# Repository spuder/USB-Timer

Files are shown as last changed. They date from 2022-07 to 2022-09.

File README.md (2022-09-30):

# USB-Timer

Control 4 USB ports with a microcontroller








Buy your own:   




## Hardware

USB-Timer is based on a Wemos D1 Mini. It uses 4 N Channel Mosfets to control multiple USB ports

| **Microcontroller**: | Count | 
| --- | --- |
| [Wemos D1 Mini](https://www.amazon.com/MakerFocus-NodeMcu-Development-ESP8266-Compatible/dp/B07KW54YSK) | 1x | 

| **Mosfets**: | Type | Count | 
| --- | --- | --- |
| [IRLZ34N N Channel Mosfet ](https://www.amazon.com/BOJACK-IRLZ34N-IRLZ34NPBF-N-Channel-transistors/dp/B08L8S3154) |Through Hole| 4x|
| [NTR4501NT1G N Channel Mosfet](https://www.mouser.com/ProductDetail/863-NTR4501NT1G) |SMD | 4x |

Use either through hole _or_ SMD mosfet, not both!
*Any TTL N Channel Mosfet should work as long as it has a VGO < 3.3. volts*

| **Resitors**  | Count | 
| ---  | --- |
| [10K - 1/4 watt](https://www.mouser.com/ProductDetail/Vishay-Beyschlag/MBA02040C1002FC100?qs=nlQjf3QnJCoHnMMMaOw%2FFA%3D%3D) | 8x | 

| **USB** | Website | Count |
| --- | --- | --- |
| [USB Type A Connector](https://www.amazon.com/gp/product/B00H51E7B0/ref=ewc_pr_img_3?smid=ATVPDKIKX0DER&psc=1) | Amazon | 4x | 
| [USB mini](https://www.mouser.com/ProductDetail/798-ZX62D-B-5PA830) | Mouser | 1x | 
| [USB Mini Easy Solder](https://www.amazon.com/Micro-Interface-Adapter-Breakout-Module/dp/B07B5ZDLJY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) | Amazon | 1x | 

| **Buttons (optional)** | Website | Count | 
| --- | --- | --- |
| [8mm metal buttons](https://www.aliexpress.com/item/3256801677651364.html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) | Aliexpress | 4
| [Rubber Feet](https://www.amazon.com/gp/product/B07G86DL1L/ref=ppx_yo_dt_b_asin_title_o00_s00?ie=UTF8&psc=1) | Amazon | 100| 

See [PCB/BOM](./PCB/BOM) for full Bill of Materials

### Schematic





Board was designed with [Easy EDA](https://easyeda.com/)

View project on [OSHWLab.com/owenspencer/USB-Timer](https://oshwlab.com/owenspencer/USB-Timer)





### Building

Order the PCB from your favorite PCB Manufacture. Cost of boards will be about $27 for 5

Popular Choices: 
- [OshPark](https://oshpark.com/)
- [JLCPCB](https://jlcpcb.com/)
- [PCBWay](https://www.pcbway.com/)

The board can be built with either surface mount or through hole components (but not both). 

For the micro USB ports, you can solder the ports directly (if you are skilled), or you can use [these through hole kits](https://www.amazon.com/gp/product/B07KS1RPMP/ref=ewc_pr_img_2?smid=AB5D7200EYCEL&psc=1)



### PinOut

```sh
USB 1 => D8 
USB 2 => D7
USB 3 => D6
USB 4 => D5
Button 1 => D1 and GND (PullUp)
Button 2 => D2 and GND (PullUp)
Button 3 => D3 and GND (PullUp)
Button 4 => D0 and 3.3v (PullDown)
```


Once the board is built, see the [Firmware/arduino/blink/README.md](Firmware/arduino/blink/README.md]) for a sketch to blink the leds. Or get started with ESPHome configuration. 

[Setup D1 Mini with arduino](https://www.instructables.com/Programming-the-WeMos-Using-Arduino-SoftwareIDE/)  

## Configuration

Configuration can be done in one of several ways

1. web.esphome.com (recomended for most users)
2. ESPHome / ESPHome + Home Assistant 
3. Arudino programming (advanced)



### Config[ESPHome]

### Web.esphome.com

The easiest way to get up and running is by plugging the USB-Timer into your computer, then navigating to [https://web.esphome.io/](https://web.esphome.io/)

Then upload the `firmware.bin` available from the releases page. 

Once the device reboots, you should find a new wireless network named 'USB-Timer Fallback Network'.

Password => `12345678`

#### Home Assistant

Setting up with HomeAssistant is easy, just install the esphome extension, then click 'add device'. 

See [./Firmware/esphome](./Firmware/esphome/) directory for example configurations

Most of the configuration is abstracted away so you don't need to worry about it. 

Some versions of home assistant default to the wrong model of esp8266. If you get errors, try commenting/deleting these lines. (or rename `esp01_1m` to  `d1_mini` )

```bash
#esp8266:
# board: esp01_1m
```

Just add an 'include' into your esphome config that references this git repo and esphome should set everything up automatically including your timezone.

```yaml
packages:
  usb-timer: github://spuder/USB-Timer/Firmware/esphome/packages/hardware.yaml
dashboard_import:
  package_import_url: github://spuder/usb-timer/esphome/common.yaml@main
```

Copy the api key from the HA gui and then go to 'Settings' -> 'Integrations' and you should see a new device named usb-timer1 (or whatever you named it). Paste in your api key and everything should work. 

---

#### ESPHome Stand Alone (non home assistant)

A `Makefile` is provided that will generate `firmware.bin` file which you can manually upload to your USB-Timer. 

Make sure you have `esphome` installed. OSX Users with homebrew can run `brew install esphome`. 

```bash
make clean
make build
```

This will generate 2 firmware files in the root directory

```bash
firmware.bin
firmware.elf
```

Use a tool like [https://web.esphome.io/](https://web.esphome.io/) or [esphome/esphome-flasher](https://github.com/esphome/esphome-flasher) to upload the .bin to the wemos d1 mini

If you didn't specify a wireless network, the wemos will boot up into AP mode. Join the network named 'USB-Timer Fallback Hotspot' with password `12345678`. 

A captive portal will popup which will allow you to reconfigure the device to your wifi network. 



### Config[Firmware/arduino]

Code examples located in the arduino folder (Advanced users only, esphome is recomended for most users)

- [Firmware/arduino](./Firmware/arduino)  
- [Firmware/arduino/blink/README.md](arduino/blink/README.md])  
- [Firmware/arduino/wifi_manager/README.md](arduino/wifi_manager/README.md])  

## Case

STL files for a 3d printable case are located in the [CAD](./CAD/) folder



## License

This is released under the [GNU license](https://choosealicense.com/licenses/gpl-3.0/). 
You may modify and even sell comercial products, as long as it remains open source (closed source derivitives are prohibited).

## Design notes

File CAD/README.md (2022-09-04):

# CAD

The cad folder contains

- stl of pcb
- f3d files of pcb
- zip files exports from EasyEDA

The stl and f3d files were converted from EasyEDA and are only inteded to be used as rough guide for desiging cases. 

The STL's had to be converted multiple times and should not be trusted as accurate. (PCB-full is off by 1.5%). Hole placements are not guaranteed to be accurate on either model. 

Use PCB-simple since it is the more accurate of the 2 stl files. 

## Feet

The bottom has cutouts for 8mm rubber feet



[Amazon - Rubber Feet](https://www.amazon.com/gp/product/B07G86DL1L/ref=ppx_yo_dt_b_asin_title_o00_s00?ie=UTF8&psc=1)

## Assembly

Use 2 (optional) m3 screws to hold the lid in place.



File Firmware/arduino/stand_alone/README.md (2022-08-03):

# stand_alone

Stand alone is an arduino sketch to programtically turn on and off the usb ports on a schedule. 
It synchronizes with an NTP server

wifi_manager is more intellegent and is easier for many people to interface with. However it is currently a work in progress.

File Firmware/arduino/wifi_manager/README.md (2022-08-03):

# Wifi Manager

**Work in Progress**

Many features are stil being worked on. Pull requests welcome

## Objective: Program the USB-Timer without needing a computer

1. Join the Wifi Network named 'USB-Timer'
2. Navigate to the ip address of the device (iOS will automatcially open a captive portal)
3. Program in the times you want the device to turn on and off





## Reconfiguration

To reconfigure, navigate to the ip address of the device on your network

Alternativly press the physical button on the corner of the USB-Timer PCB. A wireless network will appear named USB-Timer. Once done configuring, reboot and the network will disappear.

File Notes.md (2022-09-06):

## Resources

- Add USB C to your usb 2.0 projects https://idyl.io/how-to-add-usb-type-c-micro-usb-replacement/

- [Alternative USB Micro Kit](https://www.amazon.com/Teansic-24Models-Connector-Connectors-Samsung/dp/B089Q99ZHS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)

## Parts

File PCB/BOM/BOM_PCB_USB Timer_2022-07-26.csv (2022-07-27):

ID | Name | Designator | Footprint | Quantity | Manufacturer Part | Manufacturer | Supplier | Supplier Part | Price
1 | NTR4501NT1G | Q1-B,Q2-B,Q3-B,Q4-B | SOT-23-3_L2.9-W1.3-P1.90-LS2.4-BR | 4 | NTR4501NT1G | ON | LCSC | C85416 | 0.134
2 | Header-5x1-2.54mm | U5,U6,U7,U8 | HEADER-5X1-2.54MM | 4
3 | LED_5MM | LED1,LED2,LED3,LED4 | LED-TH_BD5.0-P2.54-FD_C9900023552 | 4 | LED_5MM | null | LCSC | C9900023552
4 | IRLZ34N | Q1-A,Q2-A,Q3-A,Q4-A | IRLZ34N | 4
5 | 330Ω | R1,R3,R5,R7 | AXIAL-0.6 | 4 | EWWR0001J20R0T9 | ResistorToday | LCSC | X16151710
6 | 10KΩ | R2,R4,R6,R8 | AXIAL-0.6 | 4 | EWWR0001J20R0T9 | ResistorToday | LCSC | X16151710
7 | Header-8x1-2.54mm | U1,U2 | HEADER-8X1-2.54MM | 2
8 | Button-6x6x8-Right-Angle | SW1 | SW-TH_BBJ-C71833 | 1 | 6*6*8Plastic head,260G, 0.25mm,Side bracket | BBJ | LCSC | C71833 | 0.023
9 | Button-6x6x6mm | SW2 | SW-TH_4P-L6.0-W6.0-P4.50-LS6.1 | 1 | Switch,6*6*6Plastic head,260G, 0.25mm,Straight line | BBJ | LCSC | C71836 | 0.017
10 | EduCiaaPE_OSHWA | #G1 | LOGO_OSHWA | 1
11 | JTJ-USB-AF-90-07 | USB3_TH,USB5_TH,USB7_TH,USB1_TH | USB-A-TH_C42650 | 4 | JTJ-USB-AF-90-07 | LCSC | LCSC | C42650 | 0.041
12 | WEMOS-D1-MINI | 1 | WEMOS-D1-MINI | 1
13 | ZX62D-B-5PA8(30) | USB2,USB4,USB6,USB8 | MICRO-USB-SMD_ZX62D-B-5PA8-30 | 4 | ZX62D-B-5PA8(30) | HRS(Hirose) | LCSC | C132350 | 0.299

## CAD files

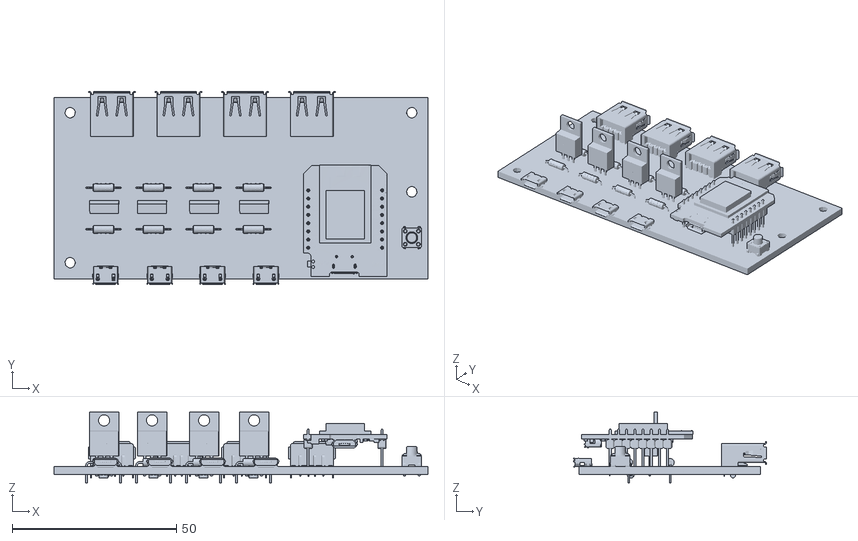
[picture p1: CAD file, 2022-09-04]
CAD/PCB/PCB-full.stl
113.9 x 58.8 x 21.5

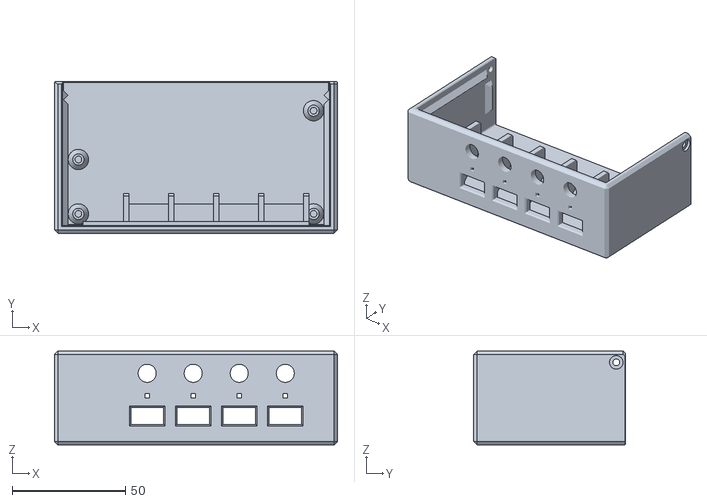
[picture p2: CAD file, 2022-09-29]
CAD/Case/Case-Lower.stl
125.0 x 67.0 x 41.5

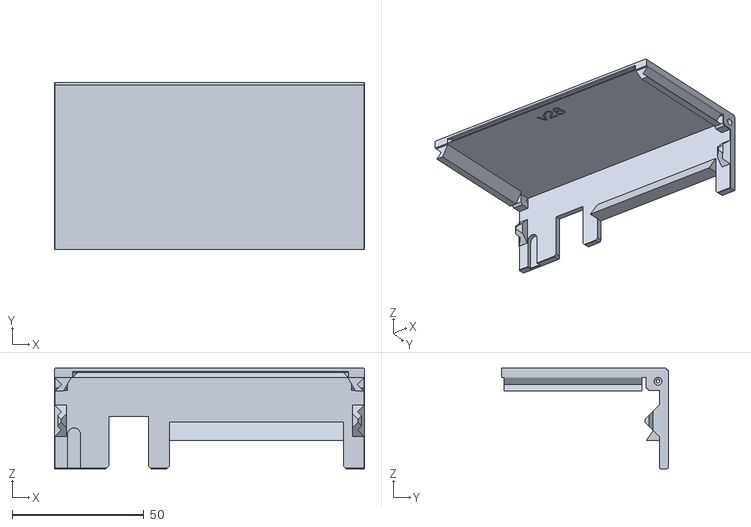
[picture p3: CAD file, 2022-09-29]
CAD/Case/Lid.stl
117.8 x 63.5 x 38.2

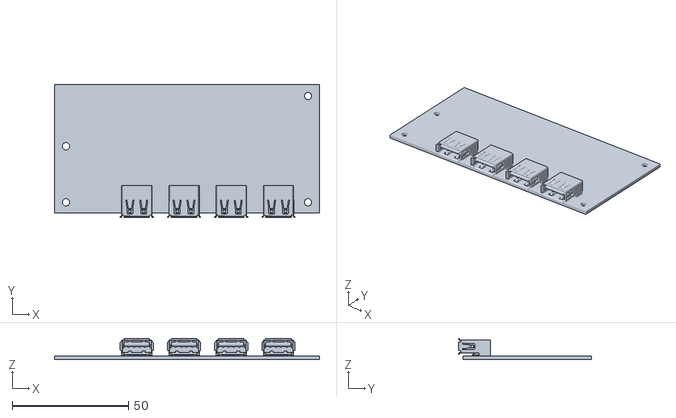
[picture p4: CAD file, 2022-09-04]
CAD/PCB/PCB-simple.stl
113.7 x 57.0 x 9.13

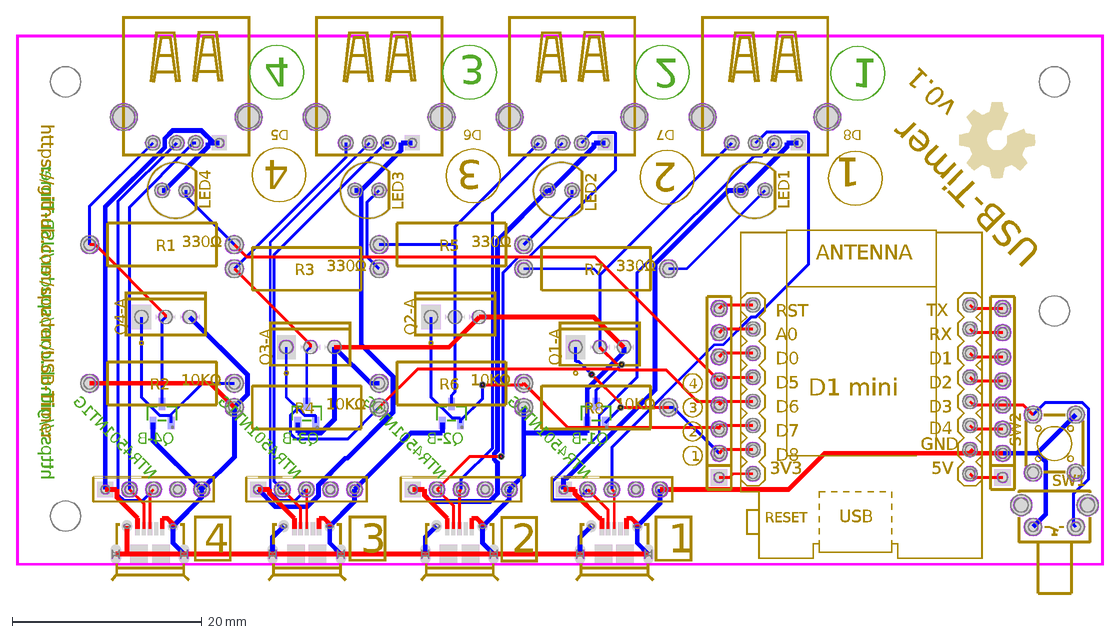
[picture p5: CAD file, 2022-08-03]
CAD/PCB/PCB_USB Timer_2022-07-30.dxf
1
2
3
4
https://github.com/spuder/USB-Timer
D8
D7
D6
D5
USB-Timer
v0.1
NTR4501NT1G
Q1-B
Q2-B
Q3-B
Q4-B
LED1
LED2
LED3
LED4
Q1-A
Q2-A
Q3-A
Q4-A
330Ω
R1
10KΩ
R2
R3
R4
R5
R6
R7
R8
SW1
SW2
3V3
RST
5V
USB
RESET
D1 mini
ANTENNA
A0
D0
TX
RX
D1
D2
D3
D4
GND

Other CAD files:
CAD/Case/Case v27.f3z
CAD/Case/Case-Upper.f3d

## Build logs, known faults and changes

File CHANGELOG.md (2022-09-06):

# v0.2

- Fix problem where port 4 doesn't work
- Move rear USB ports slightly away from the corner mounting hole
- Change resistor footprint to smaller resistor size
- Removed incorrect `sw` silkscreen in corner 
- Add visual indicators for screw holes
- Labeled Wifi Reset Button
- Added blink and wifi_manager examples
- Added esphome examples
- Add 3d printable Case
- Initial Release on Tindie.com
# v0.1

Initial release

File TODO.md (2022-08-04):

- [ ] Allow powering from single USB port (no data mode)
- [ ] Solder bridge pads between usb pin 4 and pin 5 to support 4 pin connections
- [ ] USB C support
- [ ] Surface mount reistors on bottom

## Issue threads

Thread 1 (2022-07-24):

Add USB C

spuder, 2022-07-24:
Leaving out USBC on version 1.0

Try and get it added for version 2.0

## Ideas

- Make board double sided.
  - Side 1 is through-hole USB-A/Micro USB
  - Side 2 is SMD USB-A/USB-C

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

https://idyl.io/how-to-add-usb-type-c-micro-usb-replacement/

"TYPE-C-31-M-12"

spuder, 2022-07-26:
https://youtube.com/clip/UgkxlFIEWPlVj1cm2jhy54jK28nfPjt_1yc5

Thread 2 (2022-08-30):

Bad wire on v1

spuder, 2022-08-30:
v0.1 mistakenly had a wire going to the wrong port on usb port 4 which casued the output to be reversed

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

spuder, 2022-08-30:
Solution is to cut the red trace between R1 and D4 and replace it with a wire from D4 to the left most pin of the Port 4 transistor

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

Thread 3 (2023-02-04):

Not an issue, just a question befiore i start to build

robmorin, 2023-02-04:
Hello....

Nice design! I was looking for something similar to that
But i have a couple questions;

1) If all ports are active(on), can they communicate with each other, like a standard USB hub would?

2) Lets assume i have port 1 connected to a computer on one end and the other end of port 1, an external hard drive.
I copy data from the computer to the external drive, and then have port one turn off.
Can I turn on port 4, which is connected to another computer and then have access to the hard drive on port 1?

If no to both or either of the above questions do you think its possible to alter your design to achieve this?

Just curious.

Thanks and have a great day!

spuder, 2024-03-09:
Hi there, I'm sorry I missed this issue.

> When a port is active are the data lines active too? Just want to make sure I understand as it looks like that from teh block diagram.

Yes, the data lines are technically always connected, but the power is cut

>If all ports are active(on), can they communicate with each other, like a standard USB hub would?

No each port is individual, there is no communication like a hub (but you could plug each of the 4 ports into a hub if you like

If you wanted to use it as a hub toggle for external drives, you could do that by plugging all 4 ports into a usb hub, then just be careful to not have 2 usb ports turned on at the same time.

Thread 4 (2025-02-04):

Design v2 PCB

spuder, 2025-02-04:
Create a v2 pcb with the following changes

1. Replace Wemos d1 mini with WaveShare S3 Zero https://www.waveshare.com/wiki/ESP32-S3-Zero
2. Remove all through hole resistors/mosfets
3. Round corners of pcb
4. Replace micro USB headers with usb c ports
  - Either USB C break out board [like this](https://www.amazon.com/Cermant-Connector-Adapter-Socket-Transfer/dp/B0CB395L99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):
 - Or Hander Solderable USB C header
5. Research alternative to `IRLZ34N` / `NTR4501NTG` mosfets as occasionally they have issue where the USB port won't power off.
6. Adjust alignment for 1x8 headers so that it can use a 2x8 header
7. Any other changes that might make it easier to assemble

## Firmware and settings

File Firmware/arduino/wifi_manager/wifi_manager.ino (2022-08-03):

//https://github.com/tzapu/WiFiManager
#include <Arduino.h>
#include <LittleFS.h>
#include <FS.h>

String readFile(fs::FS &fs, const char * path){
  Serial.printf("Reading file: %s\r\n", path);
  File file = fs.open(path, "r");
  if(!file || file.isDirectory()){
    Serial.println("- empty file or failed to open file");
    return String();
  }
  Serial.println("- read from file:");
  String fileContent;
  while(file.available()){
    fileContent+=String((char)file.read());
  }
  file.close();
  Serial.println(fileContent);
  return fileContent;
}
void writeFile(fs::FS &fs, const char * path, const char * message){
  Serial.printf("Writing file: %s\r\n", path);
  File file = fs.open(path, "w");
  if(!file){
    Serial.println("- failed to open file for writing");
    return;
  }
  if(file.print(message)){
    Serial.println("- file written");
  } else {
    Serial.println("- write failed");
  }
  file.close();
}

int data = 4; 
char timezone[40] = "-7";
char on_time[40] = "08:00";
char off_time[40] = "17:00";

#include <WiFiManager.h>
#define RESET_PIN D4
int timeout = 120; // seconds to run for

void setup() {
    if (!LittleFS.begin()) { //to start littlefs
        Serial.println("LittleFS mount failed");
        return;
    }
    data = readFile(LittleFS, "/data.txt").toInt();
    WiFi.mode(WIFI_STA); // explicitly set mode, esp defaults to STA+AP  
    // put your setup code here, to run once:
    pinMode(RESET_PIN, INPUT_PULLUP);

    WiFiManagerParameter custom_timezone("timezone", "timezone", timezone, 40);
    WiFiManagerParameter custom_on_time("on_time", "on_time", on_time, 40);
    WiFiManagerParameter custom_off_time("off_time", "off_time", off_time, 40);

    WiFiManager wm;

    wm.addParameter(&custom_timezone);
    wm.addParameter(&custom_on_time);
    wm.addParameter(&custom_off_time);

    //wm.resetSettings();
    bool res;
    res = wm.autoConnect("USB-Timer");
    if(!res) {
        Serial.println("Failed to connect");
        // ESP.restart();
    }
    //read updated parameters
    strcpy(timezone, custom_timezone.getValue());
    strcpy(on_time, custom_on_time.getValue());
    strcpy(off_time, custom_off_time.getValue());
    Serial.println("The values in the file are: ");
    Serial.println("\tmqtt_server : " + String(timezone));
    Serial.println("\tmqtt_port : " + String(on_time));
    Serial.println("\tapi_token : " + String(off_time));

}

void loop() {
    if ( digitalRead(RESET_PIN) == LOW) {
        WiFiManager wm;    
        //wm.resetSettings();
        wm.setConfigPortalTimeout(timeout);
        if (!wm.startConfigPortal("USB-Timer")) {
            Serial.println("failed to connect and hit timeout");
            delay(3000);
            ESP.restart();
            delay(5000);
        }
        Serial.println("connected...yeey :)");
    }
}

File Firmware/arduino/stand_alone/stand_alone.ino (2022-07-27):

// https://lastminuteengineers.com/esp8266-ntp-server-date-time-tutorial/
#include <NTPClient.h>
#include <ESP8266WiFi.h>
#include <WiFiUdp.h>

const char *ssid     = "WIFI NAME";
const char *password = "WIFI PASSWORD";

// Update the timezone by setting this offset in milliseconds (1 * 60 * 60 ) = 3600
// UTC -7 = -25200
// UTC -6 = -21600
// UTC -5 = -18000
// UTC -4 = -14400
// UTC -3 = -10800
// UTC -2 = -7200
// UTC -1 = -3600
// UTC = 0
// UTC +1 = 3600
// UTC +2 = 7200
// UTC +3 = 10800
// UTC +4 = 14400
// UTC +5 = 18000
// UTC +6 = 21600
// UTC +7 = 25200
const long utcOffsetInSeconds = -25200;

char daysOfTheWeek[7][12] = {"Sunday", "Monday", "Tuesday", "Wednesday", "Thursday", "Friday", "Saturday"};

// Define NTP Client to get time
WiFiUDP ntpUDP;
NTPClient timeClient(ntpUDP, "pool.ntp.org", utcOffsetInSeconds);

void setup(){
  Serial.begin(115200);
  pinMode(D5, OUTPUT); 
  pinMode(D6, OUTPUT); 
  WiFi.begin(ssid, password);

  while ( WiFi.status() != WL_CONNECTED ) {
    delay ( 500 );
    Serial.print ( "." );
  }

  timeClient.begin();
}

void loop() {

  timeClient.update();

    // Turn off pins on Saturday and Sunday
    if ( timeClient.getDay() == 0 || timeClient.getDay() == 6 ) {
      Serial.println("It is the weekend");
      showTime();
      digitalWrite(D5, LOW);
      digitalWrite(D6, LOW);
    } else {
      // Turn on pins between 8 AM and 5PM
      if ( (timeClient.getHours() >= 8) && (timeClient.getHours() <= 17 ) ) {
        Serial.println("Time to work");
        showTime();
        digitalWrite(D5, HIGH);
        digitalWrite(D6, HIGH);
      } else {
        Serial.println("Time to rest");
        showTime();
        digitalWrite(D5, LOW);
        digitalWrite(D6, LOW);
      }
    }
    // Check every minute
    //TODO: make this more intellegent to not overwhelm NTP servers
    delay(60000);
}

void showTime() {
  Serial.print(daysOfTheWeek[timeClient.getDay()]);
  Serial.print(", ");
  Serial.print(timeClient.getHours());
  Serial.print(":");
  Serial.print(timeClient.getMinutes());
  Serial.print(":");
  Serial.println(timeClient.getSeconds());
}

  

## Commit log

2022-08-03 version 0.1
    [PCB_USB Timer_2022-07-30.dxf, USB-Timer 3.fzz]
2022-09-03 Add 4 port and 2 port
    [USB-Timer 3.fzz]
2022-09-04 update pinout
    [USB-Timer 3.fzz]
2022-09-04 Document ruber feet
    [PCB-full.stl]
2022-09-04 case readme
2022-09-05 Add pinout
    [USB-Timer 3.fzz]
2022-09-06 overhaul folder structure
    [BOM_PCB_USB Timer_2022-07-26.csv, PCB-full.stl, PCB-simple.stl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]
2022-09-06 update hardware
    [hardware.yaml]
2022-09-06 fix warnings
    [hardware.yaml]
2022-09-06 fix esp82 board
2022-09-29 Add cad files
    [Case v27.f3z, Case-Lower.stl, Case-Upper.f3d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]
